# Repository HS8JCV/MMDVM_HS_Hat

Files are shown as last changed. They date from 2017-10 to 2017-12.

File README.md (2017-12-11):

# MMDVM_HS_Hat (VHF)
MMDVM_HS Hat for the Raspberry Pi (Zero)

This project forked from https://github.com/mathisschmieder/MMDVM_HS_Hat

This project provides a Raspberry Pi Hat for the [MMDVM_HS Hotspot](https://github.com/juribeparada/MMDVM_HS). It was designed for the Raspberry Pi Zero, but should work on any other Pi with the Hat interface. 

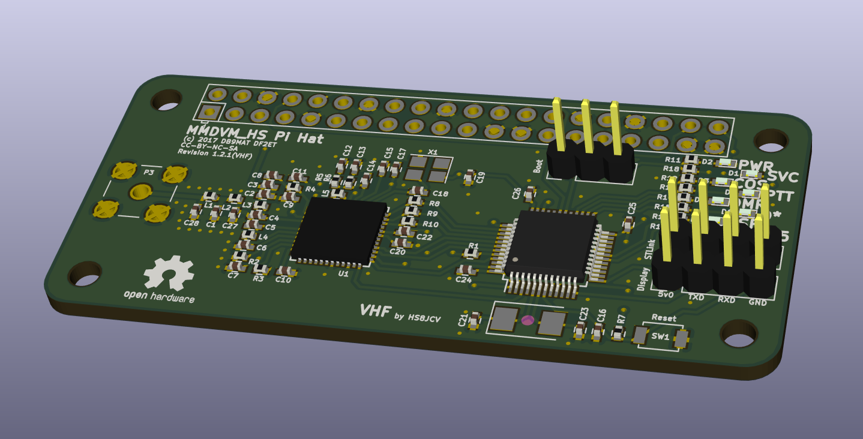
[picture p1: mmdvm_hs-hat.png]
PCB


The PCB is designed in KiCad and the necessary libraries are included. The supplied Gerber files can be used to order PCBs, for example at Elecrow or DirtyPCBs. The board's dimensions are 65x30mm.

You can order 3 beautiful, purple Revision 1.2.1(VHF) PCBs for $15 at [OSHPark](https://oshpark.com/shared_projects/D5eErGib)! 

## Revisions
If you want to know about other revisions ,Please goto  orginal repository https://github.com/mathisschmieder/MMDVM_HS_Hat
### Revision 1.2.1(VHF)
This Revision forked from revision 1.2 of https://github.com/mathisschmieder/MMDVM_HS_Hat

Detail
- Remove ceramic UHF antenna
- Add Inductor for External VCO
- Changed resistor and capacitor loop filter value
- Changed Lowpass filter circuit and value

## Customize schematic with Simulation Software
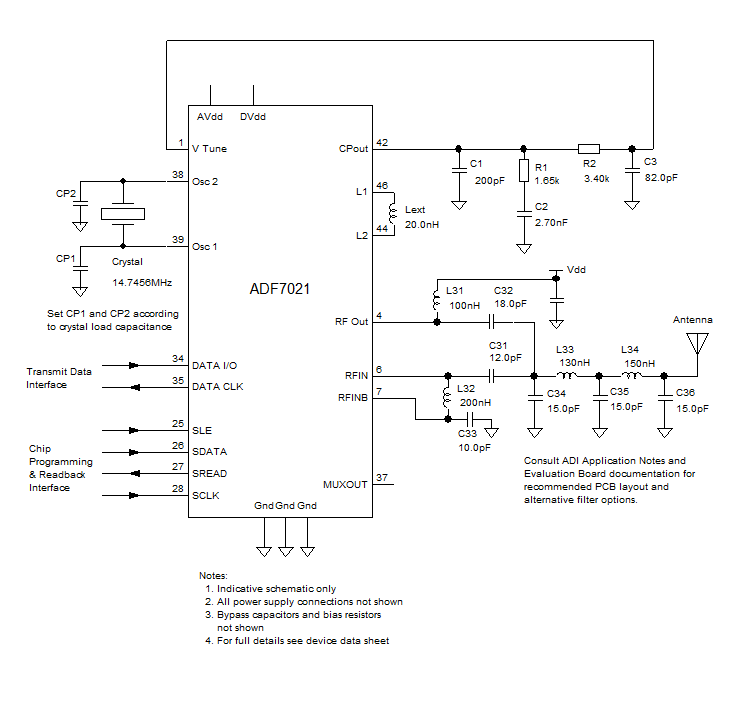
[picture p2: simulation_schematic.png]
SIM

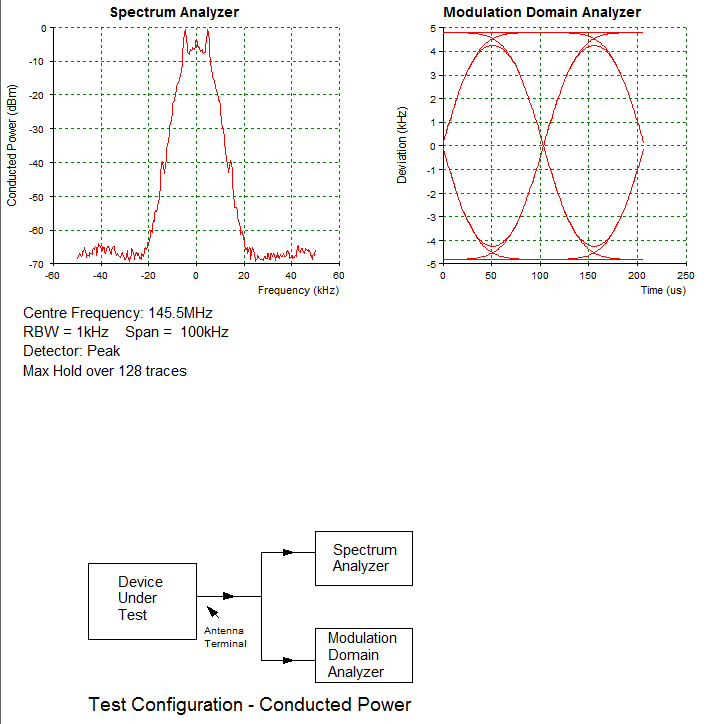
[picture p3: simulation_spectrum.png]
Spectrum


## Spectrum Result
Agilent N9340B with 20dB Attenuator

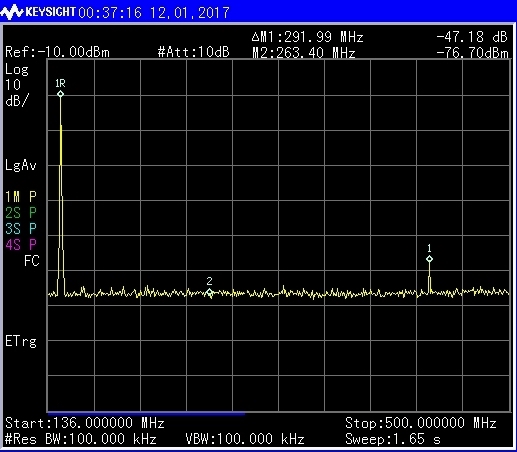
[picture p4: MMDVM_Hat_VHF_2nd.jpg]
Spur

Spurious(2nd Harmonic)

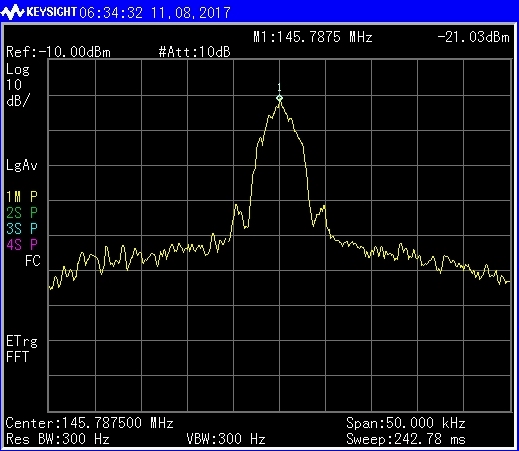
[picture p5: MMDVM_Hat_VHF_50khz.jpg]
span

50Khz Span

## BOM
* All necessary parts for the Revision 1.2.1(VHF) board can be ordered at Mouser using the following [Shopping](https://www.mouser.com/ProjectManager/ProjectDetail.aspx?AccessID=52a714bcd7)

Either the ADF7021 or the ADF7021-N can be used. Define the proper version in the firmware!

## Firmware Installation
For specific details about the firmware installation, check [these](https://github.com/juribeparada/MMDVM_HS#build-de-firmware-and-upload-to-zumspot-rpi) instructions. The process is similar to the installation on the ZumSpot Pi. 

Enable the following settings in Config.h:

    #define MMDVM_HS_HAT_REV12
    #define ENABLE_ADF7021
    #define ADF7021_14_7456
    #define STM32_USART1_HOST
    #define ENABLE_SCAN_MODE

Build the firmware:

    make

And finally upload the firmware to the MMDVM_HS_Hat:

    sudo make mmdvm_hs_hat

## License
This project is released under the Creative Commons Attribution-NonCommercial-ShareAlike 3.0 (CC-BY-NC-SA 3.0, https://creativecommons.org/licenses/by-nc-sa/3.0/) license. You may edit and share it as you like, as long as credit is given and the license is not changed. You can build as many boards for you and your friends as you like and you can even sell it to them to cover your costs, **however it is strictly forbidden to turn this into a commercial product! You are not allowed to build and sell these boards for profit!**

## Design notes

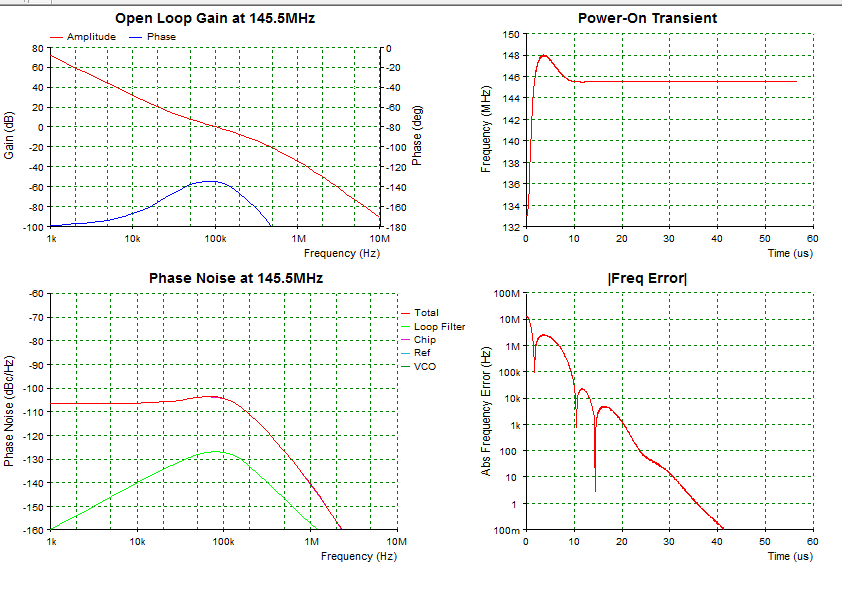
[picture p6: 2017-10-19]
simulation_pll.png

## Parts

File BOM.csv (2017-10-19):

Reference | Value | Footprint | Datasheet | MFR | MPN | SPR | SPN
U2 | STM32F103C8T6 | Housings_QFP:LQFP-48_7x7mm_Pitch0.5mm | http://www.mouser.com/ds/2/389/stm32f103c8-956229.pdf | STMicroelectronics | STM32F103C8T6 | Mouser | 511-STM32F103C8T6
Y1 | 8MHz | Crystals:Crystal_SMD_Abracon_ABM3-2pin_5.0x3.2mm | http://www.mouser.com/ds/2/3/abm3-47699.pdf | ABRACON | ABM3-8.000MHz-D2Y-T | Mouser | 815-ABM3-8-D2Y-T
C21 | 20p | Capacitors_SMD:C_0402 | http://www.mouser.com/ds/2/281/c02e-2905.pdf | Murata Electronics | GJM1555C1H200FB01D | Mouser | 81-GJM1555C1H200FB1D
C23 | 20p | Capacitors_SMD:C_0402 | http://www.mouser.com/ds/2/281/c02e-2905.pdf | Murata Electronics | GJM1555C1H200FB01D | Mouser | 81-GJM1555C1H200FB1D
P1 | BOOT0 | Pin_Headers:Pin_Header_Straight_1x03_Pitch2.54mm | http://www.mouser.com/ds/2/418/NG_CD_826629_AA_baseFilename-692251.pdf | TE Connectivity / AMP | 826629-3 | Mouser | 571-826629-3
P4 | STLINK | Pin_Headers:Pin_Header_Straight_1x04_Pitch2.54mm | http://www.mouser.com/ds/2/418/NG_CD_826629_AA_baseFilename-683270.pdf | TE Connectivity / AMP | 826629-4 | Mouser | 571-826629-4
C24 | 100n | Capacitors_SMD:C_0402 | http://www.mouser.com/ds/2/281/c03e-806517.pdf | Murata Electronics | GCM155R71C104JA55D | Mouser | 81-GCM155R71C104JA5D
C25 | 100n | Capacitors_SMD:C_0402 | http://www.mouser.com/ds/2/281/c03e-806517.pdf | Murata Electronics | GCM155R71C104JA55D | Mouser | 81-GCM155R71C104JA5D
C26 | 100n | Capacitors_SMD:C_0402 | http://www.mouser.com/ds/2/281/c03e-806517.pdf | Murata Electronics | GCM155R71C104JA55D | Mouser | 81-GCM155R71C104JA5D
R1 | 10k | Resistors_SMD:R_0402 | http://www.mouser.com/ds/2/427/dcrcwe3-109170.pdf | Vishay | CRCW040210K0FKED | Mouser | 71-CRCW0402-10K-E3
R7 | 10k | Resistors_SMD:R_0402 | http://www.mouser.com/ds/2/427/dcrcwe3-109170.pdf | Vishay | CRCW040210K0FKED | Mouser | 71-CRCW0402-10K-E3
C16 | 100n | Capacitors_SMD:C_0402 | http://www.mouser.com/ds/2/281/c03e-806517.pdf | Murata Electronics | GCM155R71C104JA55D | Mouser | 81-GCM155R71C104JA5D
R8 | 1k | Resistors_SMD:R_0402 | http://www.mouser.com/ds/2/315/AOA0000C291-1101061.pdf | Panasonic | ERJ-PA2D1001X | Mouser | 667-ERJ-PA2D1001X
R9 | 1k | Resistors_SMD:R_0402 | http://www.mouser.com/ds/2/315/AOA0000C291-1101061.pdf | Panasonic | ERJ-PA2D1001X | Mouser | 667-ERJ-PA2D1001X
R10 | 1k | Resistors_SMD:R_0402 | http://www.mouser.com/ds/2/315/AOA0000C291-1101061.pdf | Panasonic | ERJ-PA2D1001X | Mouser | 667-ERJ-PA2D1001X
C20 | 100n | Capacitors_SMD:C_0402 | http://www.mouser.com/ds/2/281/c03e-806517.pdf | Murata Electronics | GCM155R71C104JA55D | Mouser | 81-GCM155R71C104JA5D
C22 | 10n | Capacitors_SMD:C_0402 | http://www.mouser.com/ds/2/281/c02e-2905.pdf | Murata Electronics | GRM155R71H103KA88D | Mouser | 81-GRM155R71H103KA8D
D2 | green | LEDs:LED_0402 | http://www.mouser.com/ds/2/348/sml-p1-471200.pdf | ROHM Semiconductor | SML-P13PTT86R | Mouser | 755-SML-P13PTT86R
D3 | yellow | LEDs:LED_0402 | http://www.mouser.com/ds/2/348/sml-p1-471200.pdf | ROHM Semiconductor | SML-P12WTT86R | Mouser | 755-SML-P12WTT86R
D4 | red | LEDs:LED_0402 | http://www.mouser.com/ds/2/348/sml-p1-471200.pdf | ROHM Semiconductor | SML-P12U2TT86R | Mouser | 755-SML-P12U2TT86R
D5 | yellow | LEDs:LED_0402 | http://www.mouser.com/ds/2/348/sml-p1-471200.pdf | ROHM Semiconductor | SML-P12WTT86R | Mouser | 755-SML-P12WTT86R
D6 | green | LEDs:LED_0402 | http://www.mouser.com/ds/2/348/sml-p1-471200.pdf | ROHM Semiconductor | SML-P13PTT86R | Mouser | 755-SML-P13PTT86R
D7 | amber | LEDs:LED_0402 | http://www.mouser.com/ds/2/348/sml-p1-471200.pdf | ROHM Semiconductor | SML-P12DTT86R | Mouser | 755-SML-P12DTT86R
D8 | red | LEDs:LED_0402 | http://www.mouser.com/ds/2/348/sml-p1-471200.pdf | ROHM Semiconductor | SML-P12U2TT86R | Mouser | 755-SML-P12U2TT86R
R11 | 1k | Resistors_SMD:R_0402 | http://www.mouser.com/ds/2/315/AOA0000C291-1101061.pdf | Panasonic | ERJ-PA2D1001X | Mouser | 667-ERJ-PA2D1001X
R12 | 1k | Resistors_SMD:R_0402 | http://www.mouser.com/ds/2/315/AOA0000C291-1101061.pdf | Panasonic | ERJ-PA2D1001X | Mouser | 667-ERJ-PA2D1001X
R13 | 1k | Resistors_SMD:R_0402 | http://www.mouser.com/ds/2/315/AOA0000C291-1101061.pdf | Panasonic | ERJ-PA2D1001X | Mouser | 667-ERJ-PA2D1001X
R14 | 1k | Resistors_SMD:R_0402 | http://www.mouser.com/ds/2/315/AOA0000C291-1101061.pdf | Panasonic | ERJ-PA2D1001X | Mouser | 667-ERJ-PA2D1001X
R15 | 1k | Resistors_SMD:R_0402 | http://www.mouser.com/ds/2/315/AOA0000C291-1101061.pdf | Panasonic | ERJ-PA2D1001X | Mouser | 667-ERJ-PA2D1001X
R16 | 1k | Resistors_SMD:R_0402 | http://www.mouser.com/ds/2/315/AOA0000C291-1101061.pdf | Panasonic | ERJ-PA2D1001X | Mouser | 667-ERJ-PA2D1001X
R17 | 1k | Resistors_SMD:R_0402 | http://www.mouser.com/ds/2/315/AOA0000C291-1101061.pdf | Panasonic | ERJ-PA2D1001X | Mouser | 667-ERJ-PA2D1001X
C10 | 100n | Capacitors_SMD:C_0402 | http://www.mouser.com/ds/2/281/c03e-806517.pdf | Murata Electronics | GCM155R71C104JA55D | Mouser | 81-GCM155R71C104JA5D
R3 | 3k6 | Resistors_SMD:R_0402 | http://www.mouser.com/ds/2/315/AOA0000C307-1149632.pdf | Panasonic | ERA-2AEB362X | Mouser | 667-ERA-2AEB362X
C7 | 10n | Capacitors_SMD:C_0402 | http://www.mouser.com/ds/2/281/c02e-2905.pdf | Murata Electronics | GRM155R71H103KA88D | Mouser | 81-GRM155R71H103KA8D
R2 | 1k1 | Resistors_SMD:R_0402 | http://www.mouser.com/ds/2/392/susumu_RR_Data_Sheet-358748.pdf | Susumu | RR0510P-112-D | Mouser | 754-RR0510P-112D
U1 | ADF7021 | Housings_DFN_QFN:QFN-48-1EP_7x7mm_Pitch0.5mm | http://www.mouser.com/ds/2/609/ADF7021-878461.pdf | Analog Devices | ADF7021BCPZ | Mouser | 584-ADF7021BCPZ
C6 | 10p | Capacitors_SMD:C_0402 | http://www.mouser.com/ds/2/281/c02e-2905.pdf | Murata Electronics | GJM1555C1H6R8BB01D | Mouser | 81-GJM1555C1H6R8BB1D
L4 | 200n | Resistors_SMD:R_0402 | http://www.mouser.com/ds/2/597/0402af-270718.pdf | Coilcraft | 0402AF-201XJLU | Mouser | 994-0402AF-201XJLU
C5 | 12p | Capacitors_SMD:C_0402 | http://www.mouser.com/ds/2/281/c02e-2905.pdf | Murata Electronics | GRM1555C1H120FA1D | Mouser | 81-GRM1555C1H120FA1D
C4 | 18p | Capacitors_SMD:C_0402 | http://www.mouser.com/ds/2/281/c02e-2905.pdf | Murata Electronics | GRM1555C1H180JA1D | Mouser | 81-GRM1555C1H180JA1D
L2 | 130n | Resistors_SMD:R_0402 | http://www.mouser.com/ds/2/400/nductor_commercial_high-frequency_mlg1005s_en-918305.pdf | TDK | MLG1005SR13JTD25 | Mouser | 810-MLG1005SR13JTD25
L1 | 150n | Resistors_SMD:R_0402 | http://www.mouser.com/ds/2/400/nductor_commercial_high-frequency_mlg1005s_en-918305.pdf | TDK | MLG1005SR15JTD25 | Mouser | 810-MLG1005SR15JTD25
L3 | 100n | Resistors_SMD:R_0402 | http://www.mouser.com/ds/2/597/0402hp-270660.pdf | Coilcraft | 0402HPH-R10XJLW | Mouser | 994-0402HPH-R10XJLW
C3 | 220p | Capacitors_SMD:C_0402 | http://www.mouser.com/ds/2/281/c02e-2905.pdf | Murata Electronics | GRM1555C1H221JA01D | Mouser | 81-GRM1555C1H221JA01
C9 | 10n | Capacitors_SMD:C_0402 | http://www.mouser.com/ds/2/281/c02e-2905.pdf | Murata Electronics | GRM155R71H103KA88D | Mouser | 81-GRM155R71H103KA8D
C11 | 22n | Capacitors_SMD:C_0402 | http://www.mouser.com/ds/2/281/c03e-806517.pdf | Murata Electronics | GCM155R71E223KA55D | Mouser | 81-GCM155R71E223KA5D
R4 | 2r | Resistors_SMD:R_0402 | http://www.mouser.com/ds/2/427/dcrcwe3-109170.pdf | Vishay | CRCW04022R00FKED | Mouser | 71-CRCW0402-2-E3
C8 | 100n | Capacitors_SMD:C_0402 | http://www.mouser.com/ds/2/281/c03e-806517.pdf | Murata Electronics | GCM155R71C104JA55D | Mouser | 81-GCM155R71C104JA5D
C2 | 10n | Capacitors_SMD:C_0402 | http://www.mouser.com/ds/2/281/c02e-2905.pdf | Murata Electronics | GRM155R71H103KA88D | Mouser | 81-GRM155R71H103KA8D
R5 | 3.4K | Resistors_SMD:R_0402 | http://www.mouser.com/ds/2/315/AOA0000C307-1149632.pdf | Panasonic | ERA-2AEB3401X | Mouser | 667-ERA-2AEB3401X
R6 | 1.65K | Resistors_SMD:R_0402 | http://www.mouser.com/ds/2/315/AOA0000C307-1149632.pdf | Panasonic | ERA-2AEB1651X | Mouser | 667-ERA-2AEB1651X
C12 | 82p | Capacitors_SMD:C_0402 | http://www.mouser.com/ds/2/400/lcc_commercial_general_en-837201.pdf | TKD | C0402CH1C820J02C | Mouser | 810-C0402CH1C820J02C
C13 | 2.7n | Capacitors_SMD:C_0402 | http://www.mouser.com/ds/2/40/X7RDielectric-777024.pdf | AVX | 04025C272JAT2A | Taiyo Yuden | 581-04025C272JAT2A
C14 | 200p | Capacitors_SMD:C_0402 | http://www.mouser.com/ds/2/281/GCM1555C1H102FA16-01-1064253.pdf | Murata Electronics | 81-GCM1555C1H201FA6D | Mouser | 81-GCM1555C1H201FA6D
C17 | 10n | Capacitors_SMD:C_0402 | http://www.mouser.com/ds/2/281/c02e-2905.pdf | Murata Electronics | GRM155R71H103KA88D | Mouser | 81-GRM155R71H103KA8D
C15 | 100n | Capacitors_SMD:C_0402 | http://www.mouser.com/ds/2/281/c03e-806517.pdf | Murata Electronics | GCM155R71C104JA55D | Mouser | 81-GCM155R71C104JA5D
X1 | TCXO | Crystals:Crystal_SMD_3225-4pin_3.2x2.5mm | http://www.mouser.com/ds/2/122/ECS-TXO-3225-608196.pdf | ECS | ECS-TXO-3225-147.4-TR | Mouser | 520-TXO-3225-14.74T
C19 | 10n | Capacitors_SMD:C_0402 | http://www.mouser.com/ds/2/281/c02e-2905.pdf | Murata Electronics | GRM155R71H103KA88D | Mouser | 81-GRM155R71H103KA8D
C18 | 22p | Capacitors_SMD:C_0402 | http://www.mouser.com/ds/2/40/C0GNP0-Dielectric-951274.pdf | AVX | 04025A220GAT2A | Mouser | 581-04025A220G
P3 | SMA | Connectors:SMA_THT_Jack_Straight | http://www.mouser.com/ds/2/18/C901-144-8RFX-710432.pdf | TE Connectivity | 5-1814832-1 | Mouser | 571-5-1814832-1
PI1 | RPI-ZERO | pizero:RPI-Zero-RASPBERRYPI_BASTELSTUBE_V13_RASPI_BOARD_B+_FULL | http://www.mouser.com/ds/2/181/M20-783-351164.pdf | Harwin | M20-7832046 | Mouser | 855-M20-7832046
SW1 | SW_DIP_x01 | Buttons_Switches_SMD:SW_SPST_B3U-1000P | http://www.mouser.com/ds/2/307/en-b3u-3615.pdf | Omron Electronics | B3U-1000P | Mouser | 653-B3U-1000P
P2 | DISPLAY | Pin_Headers:Pin_Header_Straight_1x04_Pitch2.54mm | http://www.mouser.com/ds/2/418/NG_CD_826629_AA_baseFilename-683270.pdf | TE Connectivity / AMP | 826629-4 | Mouser | 571-826629-4
D1 | red | LEDs:LED_0402 | http://www.mouser.com/ds/2/348/sml-p1-471200.pdf | ROHM Semiconductor | SML-P12U2TT86R | Mouser | 755-SML-P12U2TT86R
R18 | 1k | Resistors_SMD:R_0402 | http://www.mouser.com/ds/2/315/AOA0000C291-1101061.pdf | Panasonic | ERJ-PA2D1001X | Mouser | 667-ERJ-PA2D1001X
L5 | 20n | Resistors_SMD:R_0402 | http://www.mouser.com/ds/2/400/nductor_commercial_high-frequency_mhq0402psa_en-1001776.pdf | TDK | MHQ0402PSA20NHT | Mouser | 810-MHQ0402PSA20NHT
C28 | 15p | Capacitors_SMD:C_0402 | http://www.mouser.com/ds/2/281/Murata%20GJM%20Series-1149669.pdf | Murata Electronics | GJM0225C1E150JB1L | Mouser | 81-GJM0225C1E150JB1L
C1 | 15p | Capacitors_SMD:C_0402 | http://www.mouser.com/ds/2/281/Murata%20GJM%20Series-1149669.pdf | Murata Electronics | GJM0225C1E150JB1L | Mouser | 81-GJM0225C1E150JB1L
C27 | 15p | Capacitors_SMD:C_0402 | http://www.mouser.com/ds/2/281/Murata%20GJM%20Series-1149669.pdf | Murata Electronics | GJM0225C1E150JB1L | Mouser | 81-GJM0225C1E150JB1L

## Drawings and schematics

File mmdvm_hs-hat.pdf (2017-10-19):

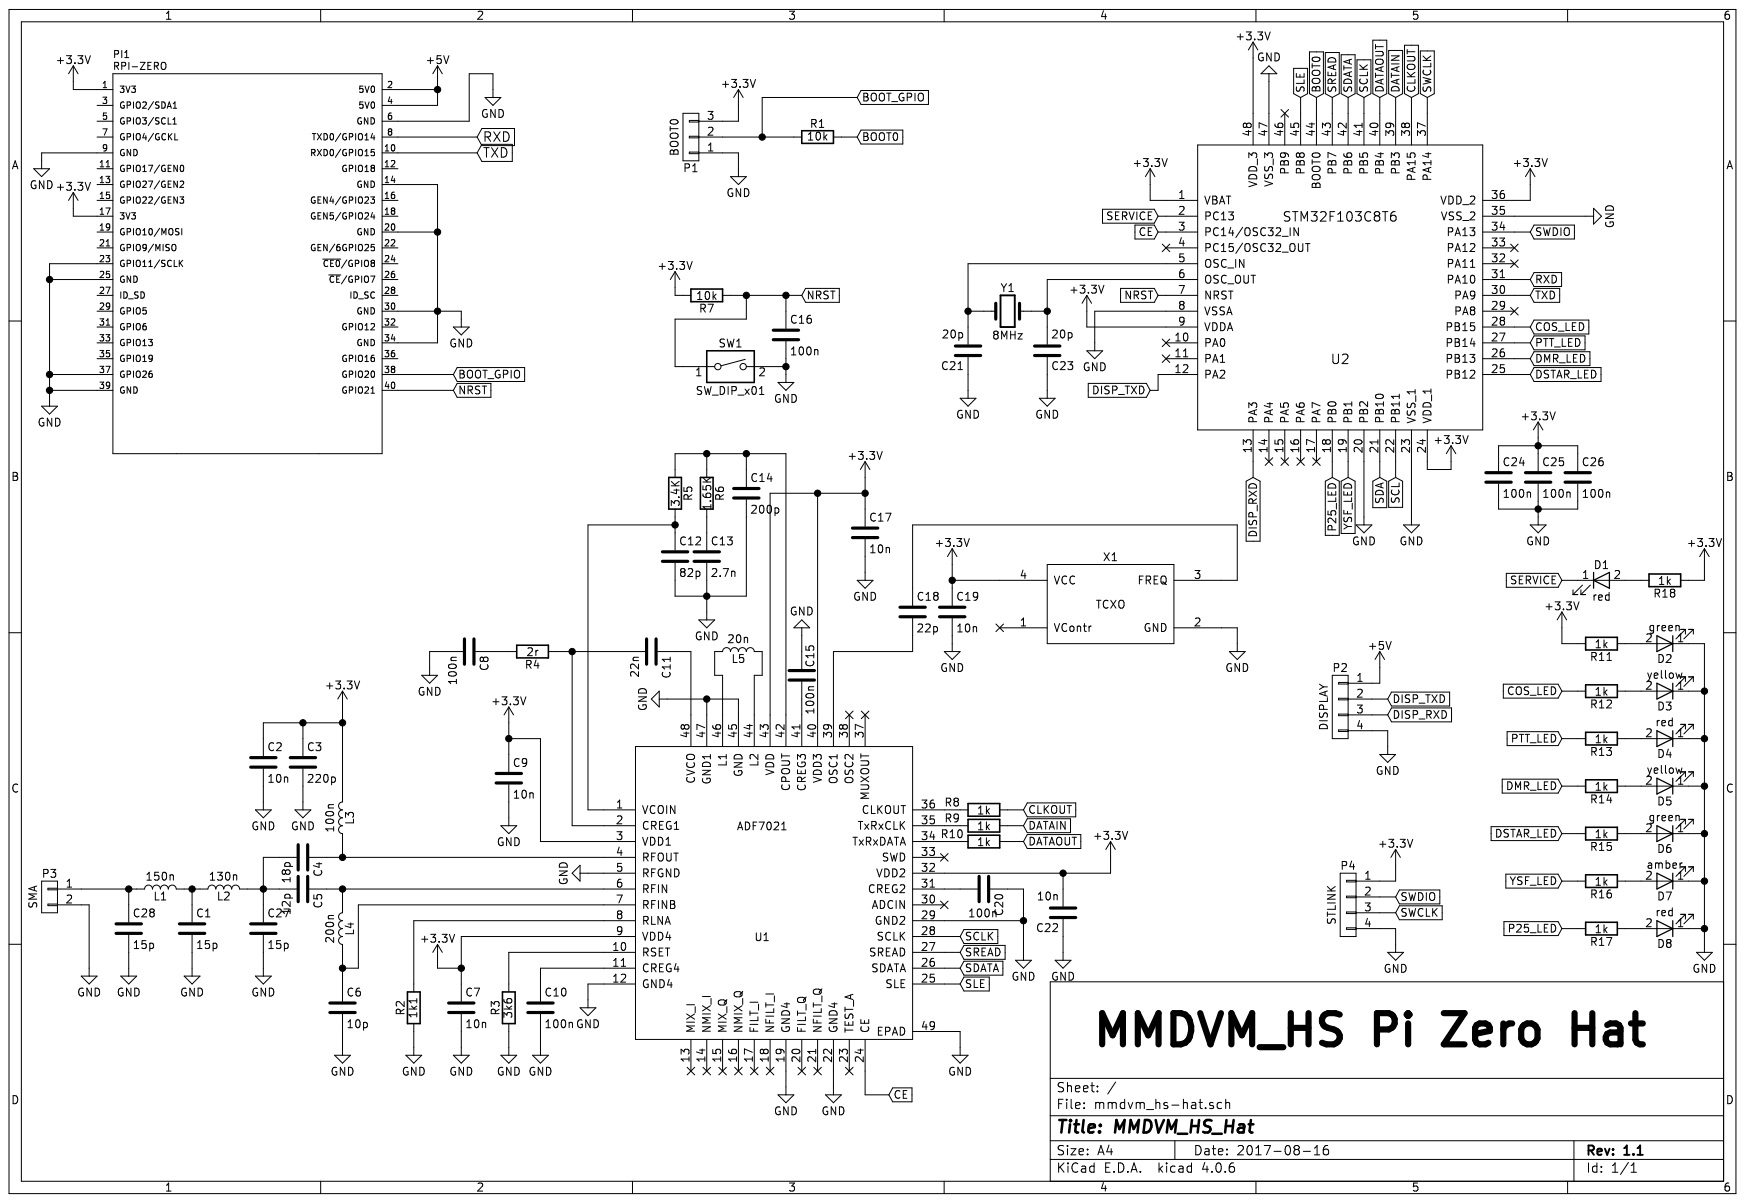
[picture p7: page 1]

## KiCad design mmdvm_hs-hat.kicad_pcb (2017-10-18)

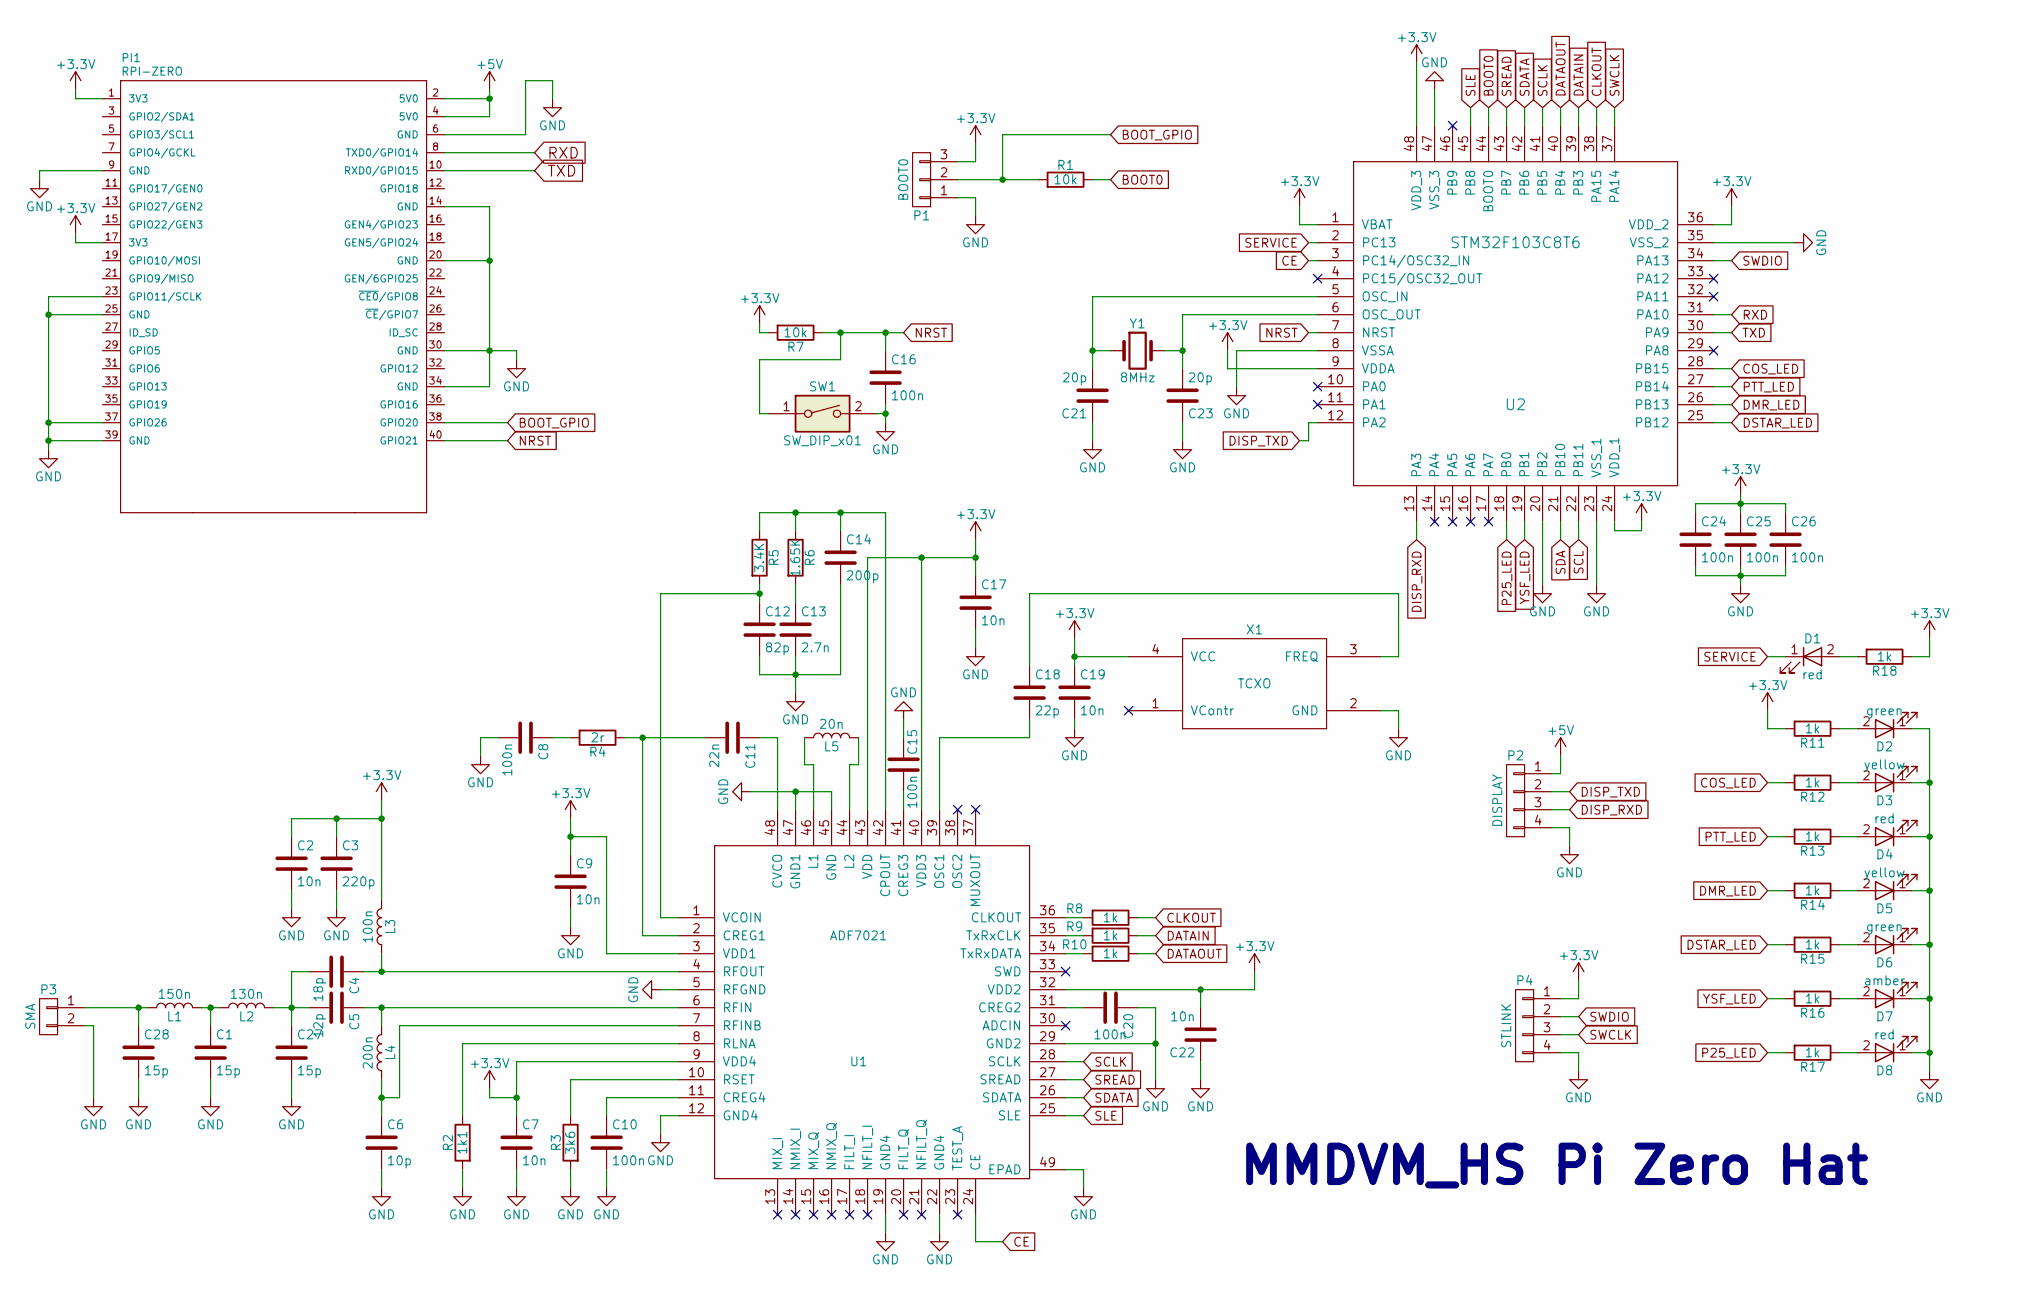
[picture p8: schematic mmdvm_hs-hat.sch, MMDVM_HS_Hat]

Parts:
C1, C27, C28: 15p; C_0402; MPN GJM0225C1E150JB1L
C2, C7, C9, C17, C19, C22: 10n; C_0402; MPN GRM155R71H103KA88D
C3: 220p; C_0402; MPN GRM1555C1H221JA01D
C4: 18p; C_0402; MPN GRM1555C1H180JA1D
C5: 12p; C_0402; MPN GRM1555C1H120FA1D
C6: 10p; C_0402; MPN GJM1555C1H6R8BB01D
C8, C10, C15, C16, C20, C24, C25, C26: 100n; C_0402; MPN GCM155R71C104JA55D
C11: 22n; C_0402; MPN GCM155R71E223KA55D
C12: 82p; C_0402; MPN C0402CH1C820J02C
C13: 2.7n; C_0402; MPN 04025C272JAT2A
C14: 200p; C_0402; MPN 81-GCM1555C1H201FA6D
C18: 22p; C_0402; MPN 04025A220GAT2A
C21, C23: 20p; C_0402; MPN GJM1555C1H200FB01D
D1, D4, D8: red; LED_0402; MPN SML-P12U2TT86R
D2, D6: green; LED_0402; MPN SML-P13PTT86R
D3, D5: yellow; LED_0402; MPN SML-P12WTT86R
D7: amber; LED_0402; MPN SML-P12DTT86R
L1: 150n; R_0402; MPN MLG1005SR15JTD25
L2: 130n; R_0402; MPN MLG1005SR13JTD25
L3: 100n; R_0402; MPN 0402HPH-R10XJLW
L4: 200n; R_0402; MPN 0402AF-201XJLU
L5: 20n; R_0402; MPN 0402AF-220XJLU
P1: BOOT0; Pin_Header_Straight_1x03_Pitch2.54mm; MPN 826629-3
P2: DISPLAY; Pin_Header_Straight_1x04_Pitch2.54mm; MPN 826629-4
P3: SMA; SMA_THT_Jack_Straight; MPN 5-1814832-1
P4: STLINK; Pin_Header_Straight_1x04_Pitch2.54mm; MPN 826629-4
PI1: RPI-ZERO; RPI-Zero-RASPBERRYPI_BASTELSTUBE_V13_RASPI_BOARD_B+_FULL; MPN M20-7832046
R1, R7: 10k; R_0402; MPN CRCW040210K0FKED
R2: 1k1; R_0402; MPN RR0510P-112-D
R3: 3k6; R_0402; MPN ERA-2AEB362X
R4: 2r; R_0402; MPN CRCW04022R00FKED
R5: 3.4K; R_0402; MPN ERA-2AEB3401X
R6: 1.65K; R_0402; MPN ERA-2AEB1651X
R8, R9, R10, R11, R12, R13, R14, R15, R16, R17, R18: 1k; R_0402; MPN ERJ-PA2D1001X
SW1: SW_DIP_x01; SW_SPST_B3U-1000P; MPN B3U-1000P
U1: ADF7021; QFN-48-1EP_7x7mm_Pitch0.5mm; MPN ADF7021BCPZ
U2: STM32F103C8T6; LQFP-48_7x7mm_Pitch0.5mm; MPN STM32F103C8T6
X1: TCXO; Crystal_SMD_3225-4pin_3.2x2.5mm; MPN ECS-TXO-3225-147.4-TR
Y1: 8MHz; Crystal_SMD_Abracon_ABM3-2pin_5.0x3.2mm; MPN ABM3-8.000MHz-D2Y-T

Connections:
+3V3: C2.1, C3.1, C7.1, C9.1, C17.1, C19.1, C22.2, C24.1, C25.1, C26.1, L3.2, P1.3, P4.1, PI1.1 (3V3), PI1.17 (3V3), R7.2, R11.2, R18.1, U1.3 (VDD1), U1.9 (VDD4), U1.32 (VDD2), U1.40 (VDD3), U1.43 (VDD), U2.1 (VBAT), U2.9 (VDDA), U2.24 (VDD_1), U2.36 (VDD_2), U2.48 (VDD_3), X1.4 (VCC)
+5V: P2.1, PI1.2 (5V0), PI1.4 (5V0)
BOOT0: R1.1, U2.44 (BOOT0)
BOOT_GPIO: P1.2, PI1.38 (GPIO20), R1.2
CE: U1.24 (CE), U2.3 (PC14/OSC32_IN)
CLKOUT: R8.1, U2.38 (PA15)
COS_LED: R12.2, U2.28 (PB15)
DATAIN: R9.1, U2.39 (PB3)
DATAOUT: R10.1, U2.40 (PB4)
DISP_RXD: P2.3, U2.13 (PA3)
DISP_TXD: P2.2, U2.12 (PA2)
DMR_LED: R14.2, U2.26 (PB13)
DSTAR_LED: R15.2, U2.25 (PB12)
GND: C1.2, C2.2, C3.2, C6.2, C7.2, C8.2, C9.2, C10.2, C12.2, C13.2, C14.2, C15.1, C16.2, C17.2, C19.2, C20.1, C21.1, C22.1, C23.1, C24.2, C25.2, C26.2, C27.2, C28.2, D2.1 (K), D3.1 (K), D4.1 (K), D5.1 (K), D6.1 (K), D7.1 (K), D8.1 (K), P1.1, P2.4, P3.2, P4.4, PI1.6 (GND), PI1.9 (GND), PI1.14 (GND), PI1.20 (GND), PI1.23 (GPIO11/SCLK), PI1.25 (GND), PI1.30 (GND), PI1.34 (GND), PI1.37 (GPIO26), PI1.39 (GND), R2.2, R3.2, SW1.2, U1.5 (RFGND), U1.12 (GND4), U1.19 (GND4), U1.22 (GND4), U1.29 (GND2), U1.45 (GND), U1.47 (GND1), U1.49 (EPAD), U2.8 (VSSA), U2.20 (PB2), U2.23 (VSS_1), U2.35 (VSS_2), U2.47 (VSS_3), X1.2 (GND)
NRST: C16.1, PI1.40 (GPIO21), R7.1, SW1.1, U2.7 (NRST)
unnamed: C1.1, L1.2, L2.1
unnamed: C4.1, L3.1, U1.4 (RFOUT)
unnamed: C5.1, L4.2, U1.6 (RFIN)
unnamed: C6.1, L4.1, U1.7 (RFINB)
unnamed: C8.1, R4.2
unnamed: C10.1, U1.11 (CREG4)
unnamed: C11.1, U1.48 (CVCO)
unnamed: C11.2, R4.1, U1.2 (CREG1)
unnamed: C12.1, R5.2, U1.1 (VCOIN)
unnamed: C13.1, R6.2
unnamed: C14.1, R5.1, R6.1, U1.42 (CPOUT)
unnamed: C15.2, U1.41 (CREG3)
unnamed: C18.1, X1.3 (FREQ)
unnamed: C18.2, U1.39 (OSC1)
unnamed: C20.2, U1.31 (CREG2)
unnamed: C21.2, U2.5 (OSC_IN), Y1.1
unnamed: C23.2, U2.6 (OSC_OUT), Y1.2
unnamed: C4.2, C5.2, C27.1, L2.2
unnamed: C28.1, L1.1, P3.1
unnamed: D1.2 (A), R18.2
unnamed: D2.2 (A), R11.1
unnamed: D3.2 (A), R12.1
unnamed: D4.2 (A), R13.1
unnamed: D5.2 (A), R14.1
unnamed: D6.2 (A), R15.1
unnamed: D7.2 (A), R16.1
unnamed: D8.2 (A), R17.1
unnamed: L5.1, U1.46 (L1)
unnamed: L5.2, U1.44 (L2)
unnamed: R2.1, U1.8 (RLNA)
unnamed: R3.1, U1.10 (RSET)
unnamed: R8.2, U1.36 (CLKOUT)
unnamed: R9.2, U1.35 (TxRxCLK)
unnamed: R10.2, U1.34 (TxRxDATA)
P25_LED: R17.2, U2.18 (PB0)
PTT_LED: R13.2, U2.27 (PB14)
RXD: PI1.8 (TXD0/GPIO14), U2.31 (PA10)
SCL: U2.22 (PB11)
SCLK: U1.28 (SCLK), U2.41 (PB5)
SDA: U2.21 (PB10)
SDATA: U1.26 (SDATA), U2.42 (PB6)
SERVICE: D1.1 (K), U2.2 (PC13)
SLE: U1.25 (SLE), U2.45 (PB8)
SREAD: U1.27 (SREAD), U2.43 (PB7)
SWCLK: P4.3, U2.37 (PA14)
SWDIO: P4.2, U2.34 (PA13)
TXD: PI1.10 (RXD0/GPIO15), U2.30 (PA9)
YSF_LED: R16.2, U2.19 (PB1)

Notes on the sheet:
MMDVM_HS Pi Zero Hat

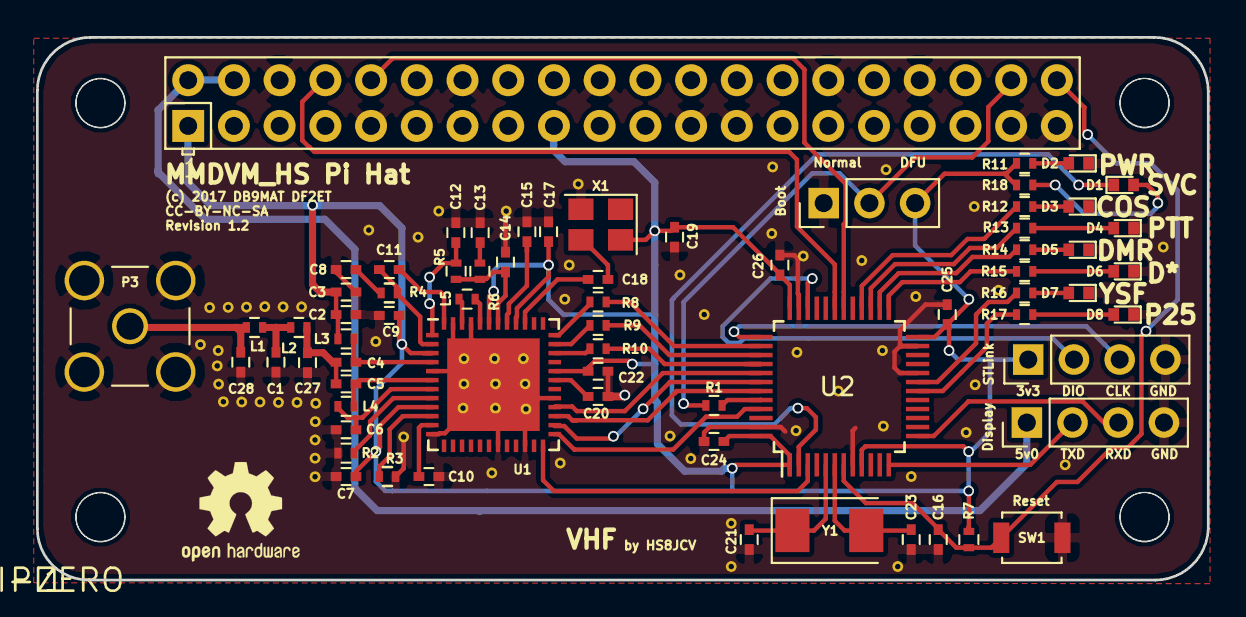
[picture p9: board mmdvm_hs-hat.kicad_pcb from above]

Board: 2 copper layers, 65.1 x 30.2 mm, 69 parts (0 on the bottom side), 61 nets.

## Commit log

2017-10-18 The commit of MMDVM Hat VHF project
    [mmdvm_hs-hat-B.Cu.gbl, mmdvm_hs-hat-B.Mask.gbs, mmdvm_hs-hat-B.Paste.gbp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]
2017-10-19 Add new BOM for VHF
    [BOM.csv]
2017-10-19 remove BOM.xlsx
    [BOM.xlsx]
2017-10-19 Edited schematic for VHF
2017-10-19 Last VHF gerber files
    [mmdvm_hs-hat-B.Cu.gbl, mmdvm_hs-hat-B.Mask.gbs, mmdvm_hs-hat-B.Paste.gbp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]
2017-12-11 Edited for last BOM
    [mmdvm_hs-hat.csv]

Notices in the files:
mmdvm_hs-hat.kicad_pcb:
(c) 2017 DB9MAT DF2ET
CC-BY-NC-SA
